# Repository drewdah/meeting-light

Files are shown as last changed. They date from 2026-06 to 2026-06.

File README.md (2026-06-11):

# Meeting Light
A professional office status display for a Waveshare ESP32-C6 1.8" Touch AMOLED, mounted in an office window. Shows your current status — Available, In a Meeting, Working From Home, Out of Office, or a custom message — to coworkers passing by.

<p align="center">
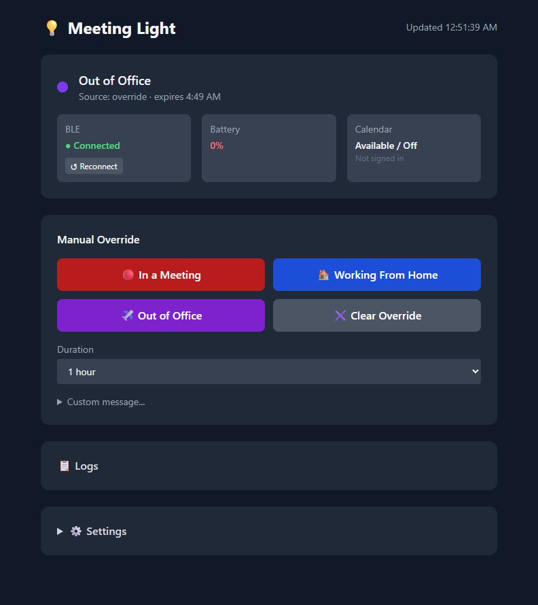
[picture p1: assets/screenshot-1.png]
Meeting Light web UI
  
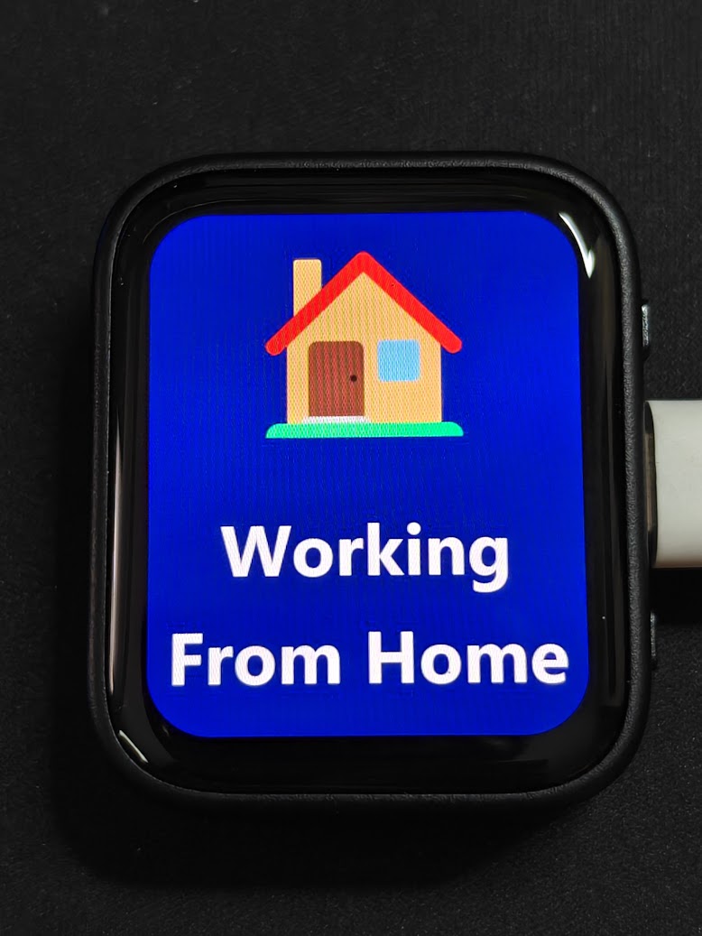
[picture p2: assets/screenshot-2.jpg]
Meeting Light on device
  
</p>

## How It Works

A mini PC at your desk polls your Outlook calendar via the Microsoft Graph API and pushes status updates to the ESP32 over BLE. A web UI (accessible remotely via Tailscale) lets you set manual overrides, compose custom messages with emoji, and preview what will appear on screen before sending.

```
ESP32-C6 AMOLED  <──BLE──>  Mini PC Service  <──Graph API──>  Microsoft 365
                                   │
                             Web UI :8080  <──Tailscale──  Remote access
```

## Features

- **Automatic detection** — polls Outlook or Google calendar for meetings, WFH location, and Out of Office status; shows **Available** when in the office with no active meeting
- **Emoji + text display** — full-resolution images rendered service-side with any emoji and custom text, transferred to the display over BLE
- **Full emoji picker** — pick any emoji from the web UI; no pre-compilation required
- **Preview before send** — see exactly what will appear on screen, with font size +/− controls
- **Calendar info card** — dashboard shows signed-in user, Teams presence, work location, and upcoming meetings at a glance
- **Manual overrides** — preset buttons (Available, In a Meeting, WFH, OOF) or custom message with background color and emoji
- **Override expiry** — set duration (30 min, 1 hr, end of day, etc.) before reverting to calendar state
- **Boot button controls** — tap to cycle through preset states; hold 3 seconds to reboot
- **Boot splash** — shows a 💡 Meeting Light logo on startup while connecting to the service
- **Waiting to Connect screen** — after the splash, shows a Bluetooth logo and the device's BLE MAC address so multiple units can be identified and configured
- **Per-device BLE name** — each device advertises as `MeetingLight-XXXX` (last 2 MAC bytes) for easy identification in BLE scanners and the service UI
- **Battery-safe deep sleep** — on battery power, sleeps and wakes every 2 minutes to advertise; never sleeps when USB is connected
- **Business hours scheduling** — device sleeps outside M–F 9–5; configurable in the web UI
- **Power monitoring** — live battery %, voltage, charging state, and USB power detection reported via BLE; dashboard shows USB Powered, Charging, or battery % as appropriate
- **Brightness control** — adjustable in Settings, applied immediately to the device
- **Real-time log panel** — connection and transfer logs visible in the web UI
- **Remote access** — web UI accessible via Tailscale from anywhere

## Display States

| State | Emoji | Background |
|---|---|---|
| Available | ☀️ | Green |
| In a Meeting | 🔴 | Red |
| Working From Home | 🏠 | Dark blue |
| Out of Office | ✈️ | Dark purple |
| Custom | Any emoji | Any color |
| Off | — | Screen off |

## Hardware

- [Waveshare ESP32-C6 Touch AMOLED 1.8"](https://www.waveshare.com/esp32-c6-touch-amoled-1.8.htm) — 368×448 AMOLED, BLE 5, two hardware buttons, LiPo connector
- Always-on mini PC at desk (Raspberry Pi, mini PC, etc.)
- 3000mAh LiPo battery, swappable; device deep-sleeps and wakes every 2 minutes to check for a connection

### Button Controls

The device has two buttons — **BOOT** (side) and **PWR** (side):

| Gesture | Action |
|---|---|
| Tap BOOT | Cycle through Off → In a Meeting → WFH → Out of Office → Available |
| Hold BOOT 3s | Reboot device |

## Enclosure

A two-piece 3D-printed case (designed in Fusion 360). Print files are in `enclosure/`:
`MeetingLight-Enclosure.3mf` (both parts, ready to import into Bambu Studio / PrusaSlicer) and individual STLs in `enclosure/stl/`.

- **Front Lid** — holds the screen and PIR sensor, and frames a paper name-plate insert. The display window is a **flush recess** so the raised cover glass sits level with the front face; a small countersunk aperture exposes the PIR's field of view without a large hole.
- **Back Tray** — holds the LiPo battery (retained by mid-edge ribs that keep the corners clear for the battery's JST wire) and mounts to a window with a command strip.
- **Joint** — the lid presses onto the tray with a self-aligning rabbet lip and snap-in detents (bumps on the lid that click into pockets in the tray walls). No screws; pops off by hand for battery swaps.
- **Overall size** — ~202 × 50 × 17 mm.

**Printing:** orient each part **standing on its end (long axis vertical)** to print without supports — the rabbet, pockets, and screen recess are all designed for that orientation. PLA/PETG, 0.2 mm layers. Detent strength is tunable: if the lid is too stiff or too loose, adjust the bump height slightly and re-export.

## Project Structure

```
firmware/       # ESP32-C6 firmware (PlatformIO + Arduino)
service/        # Mini PC service (Python + FastAPI + Docker)
enclosure/      # 3D-printed two-piece case (STL + 3MF, designed in Fusion 360)
docs/           # Architecture plan and documentation
```

## Getting Started

### Windows USB Driver Note

The ESP32-C6 uses a built-in USB-Serial/JTAG controller. On Windows, if the device doesn't appear as a COM port, install the [ESP32 board support package in Arduino IDE](https://docs.espressif.com/projects/arduino-esp32/en/latest/installing.html) which installs the correct Windows USB drivers. A reboot is required after installation.

### Firmware

Requires [PlatformIO](https://platformio.org/) with the [pioarduino](https://github.com/pioarduino/platform-espressif32) platform fork for ESP32-C6 Arduino support. The easiest approach is the PlatformIO VS Code extension.

```bash
cd firmware
pio run                          # build
pio run -t upload --upload-port COM9   # flash via USB-C (adjust port)
```

To regenerate the pre-compiled preset and boot splash images (run from repo root after changing the service rendering):
```bash
python3 firmware/tools/gen_preset_images.py   # Available, In a Meeting, WFH, OOF
python3 firmware/tools/gen_boot_splash.py     # Boot splash
```
Then reflash the firmware.

### Service

#### Prerequisites

- Python 3.11 or newer
- Bluetooth adapter (built-in or USB dongle)
- On Windows: no extra drivers needed; on Linux: `bluez` must be installed (`sudo apt install bluez`)

#### 1. Copy and edit `.env`

```bash
cd service
cp .env.example .env
```

Open `.env` and fill in your values — everything here is passed as environment variables to the container by `docker-compose`:

| Variable | Required | Description |
|---|---|---|
| `ESP32_MAC_ADDRESS` | Always | BLE MAC of your device (see *Finding Your ESP32 MAC Address* below) |
| `CALENDAR_PROVIDER` | Always | `microsoft` (default) or `google` |
| `MS_GRAPH_CLIENT_ID` | Microsoft | Azure public-client app ID — see *One-time provider setup* |
| `MS_GRAPH_TENANT_ID` | Microsoft | Your tenant GUID (Directory ID from Azure app registration Overview) |
| `GOOGLE_CLIENT_ID` | Google | OAuth client ID from Google Cloud — see *One-time provider setup* |
| `GOOGLE_CLIENT_SECRET` | Google | OAuth client secret (confidential — never commit) |
| `TIMEZONE` | Optional | IANA timezone, e.g. `America/New_York` |

#### 2. Create a virtual environment and install dependencies

```bash
# Windows
python -m venv .venv
.venv\Scripts\activate

# macOS / Linux
python3 -m venv .venv
source .venv/bin/activate
```

```bash
pip install -r requirements.txt
```

#### 3. Run the service

```bash
python -m uvicorn src.web.app:app --host 0.0.0.0 --port 8080
```

The web UI is available at `http://localhost:8080` (or `http://<your-pc>:8080` from another device on the same network / via Tailscale).

#### 4. Authenticate your calendar (first run)

1. Open the web UI and go to **⚙️ Settings → Calendar**.
2. Select your provider and click **Sign In**.
3. A device code will appear — visit the URL shown and enter the code in your browser.
4. Once authenticated the service starts polling your calendar automatically. Tokens are cached in `data/` and refreshed on subsequent runs.

#### Docker (production mini PC deployment)

```bash
docker compose up
```

The same `.env` file is used; Docker Compose passes it through automatically.

### Calendar Provider

Set `CALENDAR_PROVIDER=microsoft` (default) or `CALENDAR_PROVIDER=google` in `.env`.

The app is pre-registered for both providers — each deployer just picks a provider and
signs in; there's no cloud console work per deployment. Each person authenticates with
their own Microsoft/Google account via the sign-in flow in the web UI.

**What gets detected (priority order):**
- **Working From Home** — Teams/Outlook work location set to Home (Microsoft presence API), all-day WFH events, or [Working Location](https://support.google.com/calendar/answer/11896660) → Home Office (Google)
- **Out of Office** — OOF events or scheduled automatic replies (Microsoft); native Out of Office events (Google)
- **In a Meeting** — any busy/tentative calendar event happening right now
- **Available** — in the office with no active meeting (Microsoft only; Google defaults to Available)

#### Google Testing Mode limit

`calendar.readonly` is a Google "sensitive" scope. Until the app completes Google's
one-time verification, it runs in **Testing mode**, which means:
- Maximum **100 users** across all deployments (app-wide, not per host)
- Refresh tokens **expire every 7 days** — Gmail users must re-sign-in weekly

Each Gmail user must be added as a test user in [Google Cloud Console → OAuth consent screen](https://console.cloud.google.com/). Microsoft 365 / Outlook has no equivalent limit.

### One-time provider setup (maintainer only)

Register the app once; every deployment reuses the same credentials via `.env`. Each user
then signs in with their own account — no per-person cloud console work required.

**Microsoft** — [portal.azure.com](https://portal.azure.com) → **Microsoft Entra ID** → **App registrations** → **New registration**:

1. **Name**: anything (e.g. `Meeting Light`)
2. **Supported account types**: choose based on your account type:
   - Work/school (Microsoft 365): *Accounts in this organizational directory only*
   - Personal (Outlook.com/Hotmail) or mixed: *Accounts in any organizational directory … and personal Microsoft accounts*
3. **Redirect URI**: leave blank — click **Register**
4. Copy the **Application (client) ID** → `MS_GRAPH_CLIENT_ID` in `.env`
5. Go to **Authentication** (left sidebar):
   - Click **Add a platform** → **Mobile and desktop applications**
   - Check `https://login.microsoftonline.com/common/oauth2/nativeclient` → **Configure**
   - Scroll down to **Advanced settings** → set **Allow public client flows** to **Yes** → **Save**
6. Go to **API permissions** (left sidebar):
   - Click **Add a permission** → **Microsoft Graph** → **Delegated permissions**
   - Search and add: `Calendars.Read`, `Presence.Read`, `User.Read`, `MailboxSettings.Read`
   - Click **Grant admin consent** if the button appears (required for org accounts)

> **Tenant ID note**: set `MS_GRAPH_TENANT_ID` to your actual tenant GUID (visible on the app registration Overview page as *Directory (tenant) ID*). `organizations` does not work for single-tenant registrations. Use `common` only for multi-tenant apps that allow personal Microsoft accounts.

**Google** — [console.cloud.google.com](https://console.cloud.google.com) → new project:
- Enable the **Google Calendar API**
- Credentials → OAuth client ID → type: **TV and Limited Input devices**
- Copy the **Client ID** → `GOOGLE_CLIENT_ID` in `.env`
- Copy the **Client Secret** → `GOOGLE_CLIENT_SECRET` in `.env` (confidential — never commit)
- Add each Gmail user as a test user on the OAuth consent screen

### Finding Your ESP32 MAC Address

Power on the device — after the boot splash it shows a **"Waiting to Connect"** screen with the Bluetooth logo and the full MAC address (e.g. `FC:01:2C:FD:DD:E0`). Read it directly off the screen.

Alternatively, run the BLE scanner:
```bash
cd service
python scan.py
```
The device advertises as `MeetingLight-XXXX` (last 2 MAC bytes). Set `ESP32_MAC_ADDRESS` in `.env`, or enter it in the web UI under ⚙️ Settings and click **↺ Reconnect**. The service will also auto-discover any `MeetingLight-XXXX` device if no MAC is configured.

### Deploying on Proxmox (Docker in LXC)

This setup runs the service inside a Docker container inside a **privileged LXC container** on a Proxmox node. Bluetooth is provided by the Proxmox host's BlueZ via a shared D-Bus socket — the LXC container gets a working `/run/dbus` without running BlueZ itself.

#### Prerequisites on the Proxmox host

1. **Install BlueZ on the host** (not inside the LXC):
   ```bash
   apt install bluez
   systemctl enable --now bluetooth
   ```

2. **Bind the host D-Bus socket into the LXC** — edit `/etc/pve/lxc/<id>.conf`:
   ```
   lxc.cgroup2.devices.allow: a
   lxc.cap.drop:
   lxc.mount.entry: /dev/bus/usb dev/bus/usb none bind,optional,create=dir
   lxc.mount.entry: /dev/rfkill dev/rfkill none bind,optional,create=file
   lxc.mount.entry: /run/dbus mnt/host-dbus none bind,create=dir
   ```
   > The `/run/dbus` → `/mnt/host-dbus` indirection is required because `/run` inside the LXC is a tmpfs that gets mounted after LXC bind mounts are processed.

3. **Create a systemd mount unit inside the LXC** (`/etc/systemd/system/run-dbus.mount`) to relay the socket into `/run/dbus` at boot:
   ```ini
   [Unit]
   Description=Bind mount host BlueZ D-Bus socket
   DefaultDependencies=no
   After=tmp.mount

   [Mount]
   What=/mnt/host-dbus
   Where=/run/dbus
   Type=none
   Options=bind

   [Install]
   WantedBy=sysinit.target
   ```
   ```bash
   systemctl enable run-dbus.mount
   ```

#### Deploying the service inside the LXC

```bash
# Inside the LXC
apt install docker.io docker-compose-plugin git

# Fix Docker cgroup driver (required in LXC)
mkdir -p /etc/docker
echo '{"exec-opts": ["native.cgroupdriver=cgroupfs"]}' > /etc/docker/daemon.json
systemctl restart docker

# Clone and configure
git clone https://github.com/drewdah/meeting-light /opt/meeting-light
cp /opt/meeting-light/service/.env.example /opt/meeting-light/service/.env
# Edit .env with your MS_GRAPH_CLIENT_ID, MS_GRAPH_TENANT_ID, TIMEZONE, etc.

cd /opt/meeting-light/service
docker compose up -d
```

> **Note**: If you update `.env`, run `docker compose up -d --force-recreate` — `docker compose restart` does not reload environment files.

#### Docker Compose network mode

The service's `compose.yml` uses `network_mode: host` and `privileged: true` so the container has direct access to the LXC's D-Bus socket (`/run/dbus`) and the shared Bluetooth adapter.

## Configuration

All settings are configurable in the web UI under ⚙️ Settings:

| Setting | Default | Description |
|---|---|---|
| Business hours start | 9 | Hour (24h) to wake device |
| Business hours end | 17 | Hour (24h) to sleep device |
| Timezone | America/New_York | IANA timezone string |
| ESP32 MAC address | — | BLE MAC of the device |
| Poll interval | 60s | How often to check calendar |
| Brightness | 128 | Display brightness 0–255 |

## Architecture Notes

- **State priority**: Manual override > WFH (work location/all-day event) > OOF (auto-reply/event) > In a Meeting > Available > Schedule (sleep) > Off
- **Image transfer**: Service renders full 368×448 JPEG using Pillow (Segoe UI Emoji on Windows), transfers in ~490-byte acknowledged BLE chunks
- **Preset images**: Available, In a Meeting, WFH, OOF, and the boot splash are pre-compiled as JPEG byte arrays in firmware (`preset_images.h`, `boot_splash.h`). The boot button cycles through these instantly with no BLE transfer. Re-run the generator scripts and reflash to update them.
- **BLE**: NimBLE peripheral on ESP32, bleak central on mini PC. Custom GATT service with state command + device status characteristics
- **Power**: AXP2101 PMIC reports battery %, voltage, charging state, and USB/VBUS presence over BLE. AMOLED with mostly-dark backgrounds; device deep-sleeps and wakes every 2 minutes to advertise BLE. Deep sleep is skipped entirely when USB power is connected (VBUS detected). Hardware note: GPIO wakeup from deep sleep requires LP GPIOs (0–7) on ESP32-C6 — all are consumed by the display bus and I2C, so only RTC timer wakeup is available.

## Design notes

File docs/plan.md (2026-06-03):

# Meeting Light System - Implementation Plan

## Context

The user wants a professional-looking status display for their office window that shows coworkers (primarily CEO and HR) whether they're in a meeting, working from home, or out of office. The system uses a Waveshare ESP32-C6 1.8" Touch AMOLED (battery-powered, BLE only) controlled by a Linux mini PC at the desk that polls Outlook calendar via Microsoft Graph API. A web UI on the mini PC (accessible remotely via Tailscale) allows manual overrides and custom messages/images.

## Architecture

```
┌──────────────┐  BLE   ┌──────────────────┐  Graph API  ┌─────────────┐
│  ESP32-C6    │◄──────►│  Mini PC Service  │◄───────────►│  Microsoft  │
│  AMOLED      │        │  (Docker)         │             │  365        │
│  display     │        │                   │             └─────────────┘
└──────────────┘        │  Web UI :8080     │◄── Tailscale ── User (remote)
                        └──────────────────┘
```

**State priority**: Manual override (web UI/buttons) > Calendar-detected > Schedule-based (sleep outside hours) > Off

## Project Structure

```
meeting-light/
├── firmware/                    # ESP32-C6 (PlatformIO + ESP-IDF)
│   ├── platformio.ini
│   ├── src/
│   │   ├── main.cpp
│   │   ├── ble_service.h/.cpp   # NimBLE GATT server
│   │   ├── display.h/.cpp       # SH8601 AMOLED via esp_lcd
│   │   ├── power.h/.cpp         # AXP2101 PMIC, deep sleep
│   │   ├── state.h/.cpp         # Local state + NVS persistence
│   │   └── buttons.h/.cpp       # GPIO interrupt + debounce
│   └── include/
│       └── config.h             # Pin defs, BLE UUIDs, constants
├── service/                     # Mini PC (Python + FastAPI)
│   ├── Dockerfile
│   ├── docker-compose.yml
│   ├── requirements.txt
│   ├── src/
│   │   ├── main.py
│   │   ├── config.py
│   │   ├── graph_client.py      # MS Graph polling (MSAL + aiohttp)
│   │   ├── ble_client.py        # BLE central (bleak)
│   │   ├── state_machine.py     # State engine with priorities
│   │   ├── scheduler.py         # Business hours logic
│   │   ├── image_processor.py   # Resize/compress images for BLE
│   │   └── web/
│   │       ├── app.py           # FastAPI + routes
│   │       ├── static/
│   │       └── templates/       # Jinja2 + HTMX
│   └── tests/
└── docs/
```

## Technology Choices

| Component | Choice | Why |
|---|---|-----|
| ESP32 framework | ESP-IDF v5.3+ via PlatformIO | Full control over NimBLE power save, AXP2101 PMIC, deep sleep |
| ESP32 BLE stack | NimBLE | ~50KB less RAM than Bluedroid, built-in power save |
| Display driver | `esp_lcd` + `esp_lcd_sh8601` | Official Espressif QSPI component for SH8601 |
| Mini PC language | Python 3.12+ | Best MS Graph SDK (MSAL), excellent BLE lib (bleak), async-native |
| Web framework | FastAPI + Jinja2 + HTMX + Tailwind | Server-rendered, no JS build step, HTMX for dynamic updates |
| BLE library (PC) | bleak | Cross-platform async BLE, works in Docker with host BT passthrough |
| Graph auth | MSAL device code flow | Right pattern for headless service, auto token refresh |
| Container | Docker with `--net=host` + privileged | Required for BlueZ/BLE access |

## BLE Protocol

Custom GATT service with three characteristics:

**State Command (Write)** - opcodes:
- `0x01 SET_PRESET_STATE [state_id]` — 0=Off, 1=In Meeting, 2=WFH, 3=OOF
- `0x02 SET_CUSTOM_TEXT [r][g][b][utf8 text]` — colored background + text
- `0x03 SLEEP` — enter deep sleep
- `0x05 IMAGE_START [size][w][h][format]` — begin image transfer
- `0x06 IMAGE_CHUNK [index][payload]` — chunked data (write-without-response for speed)
- `0x07 IMAGE_END [crc32]` — finalize + verify
- `0x08 SET_BRIGHTNESS [0-255]`

**Device Status (Read + Notify)** — current state, battery %, charging flag, voltage. ESP32 notifies on every state change (serves as ACK) and periodically while awake.

**Image transfer**: Service compresses to JPEG (~30KB for 368x448), sends in ~507-byte chunks at ~50-100 KB/s. Transfer completes in under 1 second.

## Web UI

**Dashboard**: Current state, battery level, BLE connection status, Graph API status, active override countdown.

**Override panel**: Preset buttons, custom text input + color picker, image upload with preview/crop, duration selector (30m / 1h / 2h / end of day / until next calendar change / indefinite).

**Settings**: Business hours, timezone, Graph re-auth, ESP32 MAC, brightness slider, transition log.

**API endpoints** (for automation): `GET /api/status`, `POST /api/override`, `DELETE /api/override`, `GET /api/history`.

## Power Management

- **Business hours only (M-F 9-5)**: ESP32 deep sleeps nights and weekends
- **AMOLED efficiency**: All-day statuses (WFH/OOF) use mostly-black backgrounds to save power. Short-lived statuses (In Meeting) use bold colors to catch the eye of passersby. 30-50% brightness.
- **Duty cycling for all-day statuses (WFH/OOF)**: Screen on for 30s, off/dim for 90-120s, repeat. Meetings skip duty cycling (screen stays on for full duration since they're short-lived).
- **BLE tuning**: 1s connection interval idle, 100ms during image transfer, slave latency 4
- **Disable unused peripherals**: Touch controller (screen faces window), IMU (unless used for subtle burn-in prevention)
- **Target**: 1000mAh+ LiPo, battery-only operation, 1+ week battery life with duty cycling
- **Burn-in prevention**: Subtle 1-2px random shift every few minutes

## Microsoft Graph Integration

**Azure AD app registration** with delegated permissions: `Calendars.Read`, `Presence.Read`, `User.Read`, `MailboxSettings.Read`.

**Detection logic** (polled every 60s):
1. `calendarView` for current time window — busy/tentative non-all-day events = In Meeting
2. `showAs == "oof"` = Out of Office
3. Work location / all-day event location containing "home"/"remote" = WFH
4. Default = Off

**First-time auth**: Service shows device code on web UI and logs, user completes in browser, tokens cached and auto-refreshed.

## Implementation Phases

### Phase 1: ESP32 display proof-of-concept
- PlatformIO project, SH8601 init, display a static test image
- AXP2101 battery reading, deep sleep + button wake

### Phase 2: ESP32 BLE peripheral
- NimBLE GATT server, handle SET_PRESET_STATE
- ACK with battery level, test with nRF Connect app

### Phase 3: Mini PC BLE client
- Python + bleak, scan/connect/send commands
- Docker container with Bluetooth passthrough
- Verify round-trip command + ACK

### Phase 4: Web UI basics
- FastAPI + HTMX dashboard
- Connection/battery status display
- Preset override buttons with expiry timer

### Phase 5: Microsoft Graph integration
- MSAL device code auth flow
- Calendar polling + state machine
- Business hours scheduling

### Phase 6: Custom text and image support
- ESP32: text rendering with embedded font, JPEG decode (TJpgDec)
- Service: image upload/resize/compress, chunked BLE transfer
- Web UI: image upload, text input + color picker

### Phase 7: Polish and hardening
- Power optimization tuning
- Auto-reconnect on BLE disconnect
- Error handling, logging, settings page
- State transition history

### Phase 8: Production readiness
- Preset image design (professional graphics)
- Setup documentation
- Real Outlook calendar testing

## Key Risks

1. **BLE from Docker** — BlueZ in containers is finicky. Test in Phase 3 early. Fallback: run service on host with systemd.
2. **Deep sleep current** — Real-world with AXP2101 may be ~300uA vs 7uA spec. No power outlet near the window, so battery is the only option. Mitigate by disabling all unused peripherals and using 1000mAh+ LiPo. Accept weekly battery swaps.
3. **SH8601 driver** — Espressif component is v0.0.1. Fallback: port Waveshare's Arduino demo init sequence to ESP-IDF.
4. **Enterprise Graph API** — Some orgs restrict app registrations. Document exact permissions needed.
5. **AMOLED burn-in** — Mitigated by pixel shifting, dark backgrounds, and screen-off during idle.

## Verification

- **ESP32**: Flash firmware, verify display shows preset images, BLE connects from nRF Connect, battery reading is sane, deep sleep current measured with multimeter
- **Service**: `docker compose up`, authenticate via device code, verify calendar events are detected, state transitions appear in web UI, BLE commands reach ESP32
- **End-to-end**: Create a test meeting in Outlook, verify ESP32 shows "In Meeting" within 60s, verify it clears when meeting ends. Set WFH in calendar, verify display updates. Test manual override from web UI and verify it takes priority. Test override expiry reverts to calendar state.

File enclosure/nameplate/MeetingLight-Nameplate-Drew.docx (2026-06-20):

Meeting Light — Nameplate Insert

Final cut size: 194 × 46 mm (≈ 7‑ 5/8″ × 1‑ 13/16″). Slides into the right-hand channel of the front lid.

▼ Edit the text, then cut along the solid line ▼

Drew Lawton

Director of Data & Tech Operations

Solid line = cut here (194 × 46 mm). The top & bottom ~1.7 mm tucks under the retaining lips, so keep important text vertically centered (it already is).

How to use

1. Click inside the box and replace the placeholder with your name / status. Keep it vertically centered so nothing important hides under the lips.
2. Print at 100% / “Actual size.” Turn OFF “Fit to page” / “Shrink oversized pages.”
3. Check scale: the bar below should measure exactly 50 mm. If not, fix the print-scaling setting and reprint.
4. Cut along the solid outer rectangle — final piece is 194 × 46 mm.
5. Slide it into the right-hand channel of the front lid, entering from the screen end, until it stops at the far wall.

Print-scale check bar:

50 mm

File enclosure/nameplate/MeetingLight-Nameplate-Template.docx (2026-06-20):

Meeting Light — Nameplate Insert

Final cut size: 193 × 46 mm (≈ 7‑ 5/8″ × 1‑ 13/16″). Slides into the right-hand channel of the front lid.

▼ Edit the text, then cut along the solid line ▼

Drew Lawton

Director of Data & Tech Operations

Solid line = cut here (193 × 46 mm). Dashed line = visible window (~194 × 42.6 mm) — keep important text inside it; the ~1.7 mm above & below tucks under the retaining lips.

How to use

1. Click inside the box and replace the placeholder with your name / status. Font auto-centers; size it to fit inside the dashed window.
2. Print at 100% / “Actual size.” Turn OFF “Fit to page” / “Shrink oversized pages.”
3. Check scale: the bar below should measure exactly 50 mm. If not, fix the print-scaling setting and reprint.
4. Cut along the solid outer rectangle — final piece is 193 × 46 mm.
5. Slide it into the right-hand channel of the front lid, entering from the screen end, until it stops at the far wall.

Print-scale check bar:

50 mm

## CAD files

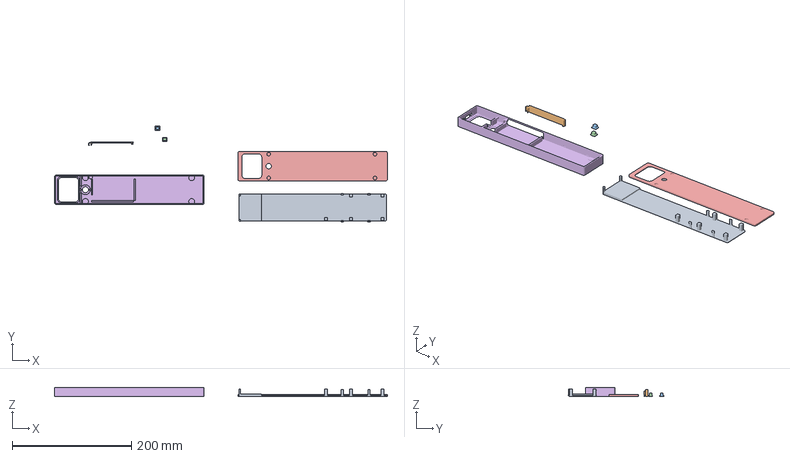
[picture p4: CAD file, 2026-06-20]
enclosure/MeetingLight-Enclosure.3mf
558.2 x 160.5 x 14.8 mm
Back Retainer
Battery Door
ButtonCap_1
ButtonCap_2
Front Cover
Front Lid

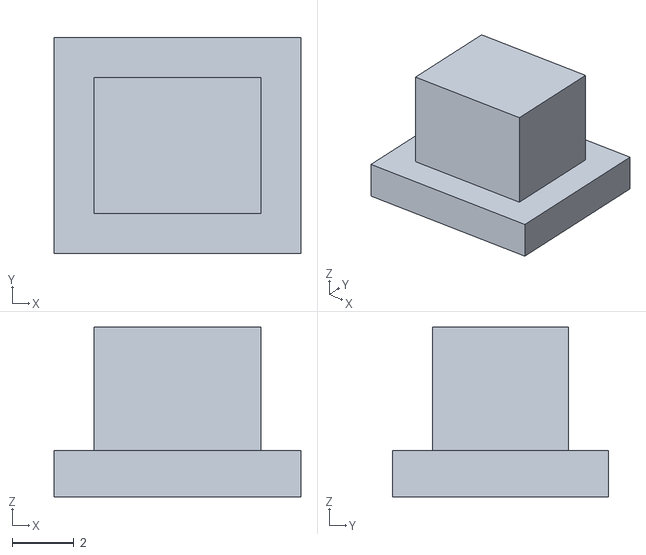
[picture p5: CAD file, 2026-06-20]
enclosure/stl/ButtonCap_1.stl
8.00 x 7.00 x 5.50

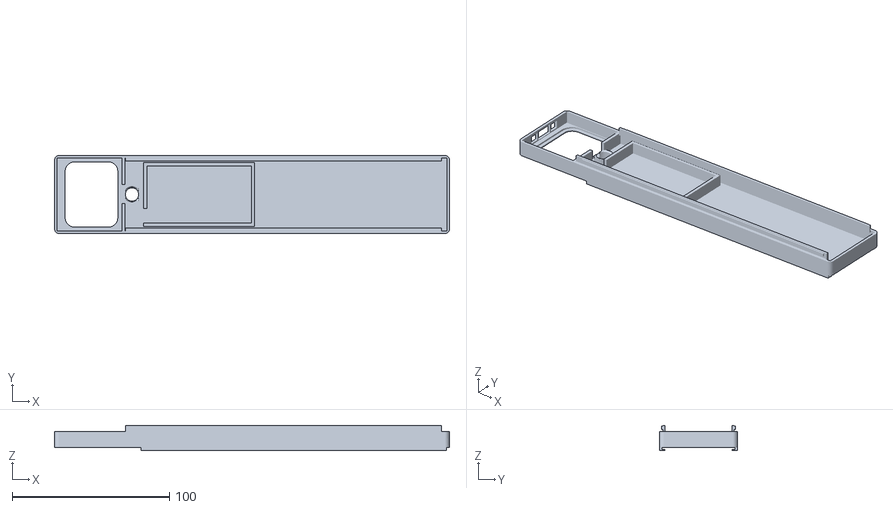
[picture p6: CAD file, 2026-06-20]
enclosure/stl/FrontLid.stl
251.0 x 49.6 x 16.0

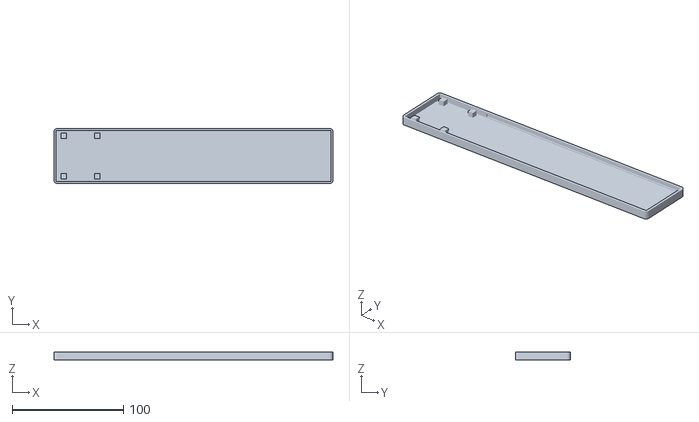
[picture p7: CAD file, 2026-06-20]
enclosure/stl/Back Tray.stl
251.0 x 49.6 x 7.00

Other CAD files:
enclosure/MeetingLight-Enclosure-v11.f3d

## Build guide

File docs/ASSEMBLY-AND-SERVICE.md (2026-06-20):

# Meeting Light — Assembly & Service Cheat Sheet

Quick reference for building, wiring, and servicing the Meeting Light enclosure.
Dimensions are measured from the current `enclosure/stl/FrontLid.stl` (v11). Last updated 2026-06-11.

---

## 1. Nameplate paper insert

| Spec | Value |
|---|---|
| **Cut size** | **194 × 46 mm** (≈ 7‑5/8″ × 1‑13/16″) |
| Visible window | ~194 × 42.6 mm (the top & bottom ~1.7 mm tuck under the retaining lips) |
| Channel location | Right-hand zone of the front lid, **X55 → X249** |
| Insertion | Slides in from the **screen end**, stops at the far wall |
| Template | [`enclosure/nameplate/MeetingLight-Nameplate-Drew.docx`](../enclosure/nameplate/MeetingLight-Nameplate-Drew.docx) |

**Printing:** Print at **100% / "Actual Size"** — turn OFF "Fit to page" / "Shrink oversized pages."
Verify with the **50 mm check bar** on the template: if it doesn't measure exactly 50 mm with a ruler, your printer is scaling and the insert will come out short. Fix the scale setting and reprint.

---

## 2. PIR sensor (AM312) — wiring & connector

### Wiring
| PIR pin | Connects to | Notes |
|---|---|---|
| **VIN** | **3V3** | Power at 3.3 V, **not 5 V** (keeps OUT at a safe 3.3 V logic level) |
| **OUT** | **GPIO17** | `PIR_PIN 17` in [`firmware/include/config.h`](../firmware/include/config.h) |
| **GND** | **GND** | |

- ⚠️ **AM312 pin order varies by board** (`GND-OUT-VCC` vs `VCC-OUT-GND`). Match **your** board's silkscreen — do not trust an online photo or a connector's "pin 1."
- The PIR is **not a wake source** — it's read while the screen is already awake to drive the sleep timeout (`PIR_TIMEOUT_MS = 60000`, 1 min no-motion → display off). A cold/iffy joint just shows up as "no motion" in the logs; low-consequence to get wrong on the first try and reflow.

### Make it swappable (one connector, at the PIR)
You only need ONE connector. Solder the pigtail to the board **once**; the connector at the PIR end is what makes the sensor swappable.

```
ESP32 board ──solder once──┐                       ┌── PIR sensor
 GPIO17 ──────────────────[ wires ]──[ connector ]── 3-pin header
 3V3   ──────────────────[ wires ]──[  (keyed)  ]──
 GND   ──────────────────[ wires ]──┘                       └──
        (do this once)                unplug here to swap the PIR
```

**Path 1 — fastest, no crimp tool, no soldering the PIR:** a 3‑pin **servo extension lead**. Female end plugs onto the PIR's existing 0.1″ pins (semi-keyed); cut the male end off and solder those 3 wires to the board.

**Path 2 — keyed JST‑XH, the "do it once properly" version:** solder a 3‑pin **XH PCB header** onto the PIR, crimp an XH pigtail (keyed + latched, can't reverse-power), plug together, solder the pigtail's other end to the board. Needs a crimp tool (reusable).

> ⚠️ **Connector clearance:** the PIR sits in the slotted collar with pins clipped short. A bulky connector body may not fit right behind the PCB. The servo housing is chunkiest; JST‑XH is more compact; a **right-angle XH header** is best. If tight, put the connector a few cm away on short flying leads, out in the open lid cavity over the nameplate.

### Soldering checklist (the screen is NOT electrically at risk — these 3 nets don't touch the AMOLED)
1. **Power off, unplug USB, disconnect the battery** first.
2. **Pre-tin** the pad AND the wire separately, then join in ~1 s. (This is the anxiety-killer — no juggling.)
3. **Hot & fast:** ~350–370 °C, in and out under 2 s per joint. A *cool* iron held for 8 s does far more damage than a hot one for 2.
4. Use **thin 30 AWG silicone wire** — it won't lever the pad up like stiff wire.
5. **Protect the glass:** board face-down on a microfiber cloth, no hard point pressing under the AMOLED.
6. **Strain relief:** dab of hot glue / strip of Kapton over the wires.
7. **Verify before power:** loupe for solder bridges; multimeter continuity check that 3V3 / GND / GPIO17 aren't shorted to each other.

---

## 3. Battery — service extension cable

The board's battery port is an **MX1.25 2-pin** connector (1.25 mm pitch — confirmed on the
[Waveshare ESP32‑C6‑Touch‑AMOLED‑1.8 wiki](https://docs.waveshare.com/ESP32-C6-Touch-AMOLED-1.8)).
The on-board JST is tiny and awkward to cycle. Fix: plug a **male-to-female extension** into the board **once**, leave it, and do all battery swaps at the accessible extension end.

### ⚠️ Polarity — the one connector where a mistake can damage hardware
The extension only needs to be **straight-through (red → red, black → black)**. If it is, it's electrically invisible — whatever orientation your battery plugs in directly today works identically through it.

Before the **first** battery connection through the extension:
1. **Trace the wire colors** at both housings — red must land on the same pin at each end.
2. Better, **meter it:** continuity from one end's red pin to the other end's red pin; confirm red is NOT tied to black.
3. **Dry-fit unpowered:** one end must plug into the board where the battery was; the other end must accept the battery's plug.

### Practical notes
- **Strain-relieve the board end** (hot glue / Kapton) — that tiny MX1.25 is fragile and you'll never unplug it again, so don't let months of tugging stress its solder pads.
- **Never short the loose leads.** Treat the bare cell with respect; never bridge the two contacts with a tool.
- 20 cm is generous — coil the slack behind the nameplate area (it's empty) or trim-to-length later (after confirming fit + function).

---

## 4. Parts list (Amazon)

> Links were live as of 2026-06-11; verify contents/photos before buying — "male/female" naming on these is inconsistent. The links are listings, not endorsements.

### PIR connector
| Path | Part | Link |
|---|---|---|
| 1 (simplest) | 3‑pin servo male-to-female leads, 150 mm (10‑pk) | [B08RDNF5ZK](https://www.amazon.com/10pcs-Servo-Extension-Female-Futaba/dp/B08RDNF5ZK) |
| 2 (keyed JST‑XH) | WayinTop SN‑28B crimp kit + JST‑XH + DuPont | [B07VND42CF](https://www.amazon.com/WayinTop-Crimping-Connector-Connectors-28-18AWG/dp/B07VND42CF) |
| 2 (alt) | SN‑28B tool + JST‑XH terminal kit (2010 pc) | [B0FM3NYHBH](https://www.amazon.com/Sn-28b-Crimping-Pliers-Set-1550pcs-Connector/dp/B0FM3NYHBH) |
| 2 (no tool) | daier JST‑XH 3‑pin set w/ wire — *confirm it includes a PCB header* | [B01DUC1PGC](https://www.amazon.com/Sets-2-5-3-Connector-200mm-Female/dp/B01DUC1PGC) |

### Battery extension
| Part | Link |
|---|---|
| **BHUPWZE MX1.25 2‑pin male-to-female extension, 20 cm (10‑pk)** — the one | [B0FZNRT2JT](https://www.amazon.com/BHUPWZE-MX1-25-Extension-1-25mm-Connector/dp/B0FZNRT2JT) |
| XUGERIP MX 1.25 2‑pin, pre-crimped 100 mm leads (backup) | [B0DMSYJZ4T](https://us.amazon.com/XUGERIP-1-25mm-Connector-Connectors-Extension/dp/B0DMSYJZ4T) |
| Cermant MX1.25 connector + pre-crimped cable kit (assortment) | [B0DSFNXRQ5](https://www.amazon.com/Cermant-MX1-25mm-Connectors-Pre-Crimped-Premium/dp/B0DSFNXRQ5) |

### Wire
| Part | Link |
|---|---|
| Striveday 30 AWG silicone hook-up wire | [B01KQ2JPY8](https://www.amazon.com/StrivedayTM-Flexible-Silicone-electronic-electrics/dp/B01KQ2JPY8) |
| TUOFENG 30 AWG silicone wire, 6 colors | [B07G2SWB19](https://www.amazon.com/TUOFENG-30awg-Stranded-Wire-Kit/dp/B07G2SWB19) |

---

## 5. Pin quick reference

| Signal | Pin | Source |
|---|---|---|
| PIR OUT | GPIO17 | `config.h` → `PIR_PIN` |
| BOOT button | GPIO9 (active LOW) | board |
| Touch INT | GPIO15 | board |
| I2C | SCL=7, SDA=8 | board |
| Battery | MX1.25 2‑pin, AXP2101 PMIC | board |

*Full hardware/firmware details live in the project memory overview and the repo `README`.*

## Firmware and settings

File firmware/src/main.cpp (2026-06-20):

#include <Arduino.h>
#include <Wire.h>
#include <esp_system.h>
#include "config.h"
#include "display.h"
#include "power.h"
#include "ble_service.h"
#include "state.h"
#include "buttons.h"
#include "audio.h"
#include "pir.h"

// Crash loop detection: RTC_NOINIT_ATTR survives software resets but is cleared on power-on.
// After 3 consecutive crash resets we enter safe mode (stable screen, no retry) to prevent
// USB re-enumeration thrashing that corrupts the Windows driver state.
#define CRASH_MAGIC    0xDEADC0DE
#define CRASH_LIMIT    3
#define SAFE_MODE_MS   30000  // reset counter after this many ms of clean uptime

RTC_NOINIT_ATTR static uint32_t crash_magic;
RTC_NOINIT_ATTR static uint32_t crash_count;

static bool safe_mode = false;
static unsigned long boot_ok_start = 0;
static bool audio_status_logged = false;

// Boot phase: track splash → waiting → done transition
enum BootPhase { BOOT_SPLASH, BOOT_WAITING, BOOT_DONE };
static BootPhase boot_phase = BOOT_DONE;
static unsigned long splash_start = 0;
static bool pir_display_blanked = false;

// Apply the saved NVS state to the display (used when exiting boot phases)
static void show_saved_state() {
    DisplayState saved = state_get_current();
    if (saved == STATE_OFF) {
        display_off();
    } else if (saved == STATE_IN_MEETING || saved == STATE_WFH ||
               saved == STATE_OOF       || saved == STATE_AVAILABLE) {
        display_on();
        display_show_preset(saved);
    } else {
        // CUSTOM_TEXT / CUSTOM_IMAGE: payload isn't persisted locally —
        // just turn the display on and wait for the app to push the content.
        display_on();
    }
}

static unsigned long last_battery_report = 0;
static const DisplayState PRESET_CYCLE[] = {
    STATE_OFF, STATE_IN_MEETING, STATE_WFH, STATE_OOF, STATE_AVAILABLE
};
static const uint8_t PRESET_COUNT = sizeof(PRESET_CYCLE) / sizeof(PRESET_CYCLE[0]);
static uint8_t cycle_index = 0;

static void on_boot_button() {
    pir_reset_timer();
    pir_display_blanked = false;

    cycle_index = (cycle_index + 1) % PRESET_COUNT;
    DisplayState new_state = PRESET_CYCLE[cycle_index];
    state_set(new_state);

    if (new_state == STATE_OFF) {
        display_off();
    } else {
        display_on();
        display_show_preset(new_state);
    }

    audio_play_state_chime();
    state_save_to_nvs();

    ble_notify_status(new_state,
                      power_get_battery_percent(),
                      power_is_charging(),
                      power_get_battery_mv(),
                      power_is_vbus_in(),
                      pir_motion_detected());

    Serial.printf("Button: state -> %d\n", new_state);
}

void setup() {
    Serial.begin(115200);
    // Wait up to 2s for CDC terminal so startup logs aren't silently dropped
    { uint32_t t = millis(); while (!Serial && (millis() - t) < 2000) delay(10); }
    delay(200);
    Serial.println("\n=== Meeting Light v0.1.0 ===");

    // Crash loop detection
    esp_reset_reason_t reset_reason = esp_reset_reason();
    bool is_crash_reset = (reset_reason == ESP_RST_PANIC ||
                           reset_reason == ESP_RST_WDT   ||
                           reset_reason == ESP_RST_TASK_WDT ||
                           reset_reason == ESP_RST_INT_WDT);

    if (reset_reason == ESP_RST_POWERON || crash_magic != CRASH_MAGIC) {
        crash_count = 0;
        crash_magic = CRASH_MAGIC;
    } else if (is_crash_reset) {
        crash_count++;
    }

    Serial.printf("Reset reason: %d, crash_count: %lu\n", reset_reason, crash_count);

    if (crash_count >= CRASH_LIMIT) {
        // Safe mode: minimal init only — stops USB thrashing
        Serial.printf("SAFE MODE: %lu consecutive crashes, halting\n", crash_count);
        Wire.begin(I2C_SDA, I2C_SCL, I2C_FREQ);
        power_init();
        display_init();
        display_show_custom_text("SAFE MODE\nHold BOOT 3s\nto restart", 255, 80, 0, 255, 255, 255);
        safe_mode = true;
        return;
    }

    // Check wake reason — timer wakes skip the splash/chime and go straight to connect screen
    esp_sleep_wakeup_cause_t wakeup = esp_sleep_get_wakeup_cause();
    bool from_timer_wake = (wakeup == ESP_SLEEP_WAKEUP_TIMER);
    if (from_timer_wake) {
        Serial.println("Woke from periodic deep sleep timer");
    } else if (wakeup != ESP_SLEEP_WAKEUP_UNDEFINED) {
        Serial.printf("Woke from deep sleep, cause: %d\n", wakeup);
    }

    Wire.begin(I2C_SDA, I2C_SCL, I2C_FREQ);

    power_init();
    state_init();
    display_init();
    buttons_init();
    pir_init();
    ble_init();
    audio_init();

    buttons_on_boot_press(on_boot_button);

    // Restore cycle_index so button cycling and BLE stay in sync.
    DisplayState saved = state_get_current();
    for (uint8_t i = 0; i < PRESET_COUNT; i++) {
        if (PRESET_CYCLE[i] == saved) {
            cycle_index = i;
            break;
        }
    }

    if (from_timer_wake) {
        // Periodic timer wake: skip splash and chime, go straight to connect screen.
        // This avoids playing audio every N minutes and makes the wake faster.
        String mac = ble_get_mac_address();
        display_show_waiting(mac.c_str());
        boot_phase = BOOT_WAITING;
    } else {
        // Fresh boot or hardware reset: full splash + chime sequence.
        display_show_boot_splash();
        audio_play_boot_chime();
        boot_phase = BOOT_SPLASH;
    }
    splash_start = millis();

    Serial.printf("Ready. State: %d, Battery: %d%% (%dmV)\n",
                  saved, power_get_battery_percent(), power_get_battery_mv());

    boot_ok_start = millis();
}

void loop() {
    if (safe_mode) {
        // Hold BOOT 3s still works via hardware reset; just idle here
        delay(100);
        return;
    }

    // Boot-phase sequencing: splash (5s) → waiting-to-connect → done
    if (boot_phase != BOOT_DONE) {
        bool connected_now = ble_is_connected();

        if (boot_phase == BOOT_SPLASH) {
            if (connected_now) {
                // Connected during splash — skip waiting screen, show saved state
                show_saved_state();
                boot_phase = BOOT_DONE;
            } else if (millis() - splash_start >= 5000) {
                // 5s elapsed, not yet connected — show waiting screen
                String mac = ble_get_mac_address();
                display_show_waiting(mac.c_str());
                boot_phase = BOOT_WAITING;
            }
        } else if (boot_phase == BOOT_WAITING) {
            if (connected_now) {
                // BLE connected while waiting — show saved state
                show_saved_state();
                boot_phase = BOOT_DONE;
            } else if (millis() - splash_start >= 30UL * 1000UL) {
                if (power_is_vbus_in()) {
                    // USB plugged in — stay awake indefinitely, keep the connect screen visible
                    splash_start = millis();
                } else {
                    // Battery only — sleep and retry on next timer wake (every 2 min)
                    Serial.println("No BLE connection — sleeping, will retry on timer wake");
                    state_set(STATE_OFF);
                    display_off();
                    power_enter_deep_sleep();
                    return;
                }
            }
        }
    }

    // Clear crash counter once we've been running cleanly long enough
    if (crash_count > 0 && boot_ok_start > 0 &&
        (millis() - boot_ok_start) > SAFE_MODE_MS) {
        crash_count = 0;
        boot_ok_start = 0;
    }

    // Log audio status once after BLE connects (startup logs missed during power cycle)
    if (!audio_status_logged && ble_is_connected()) {
        Serial.printf("Audio init: %s\n", audio_is_ok() ? "OK" : "FAILED");
        audio_status_logged = true;
    }

    buttons_check();

    pir_set_enabled(boot_phase == BOOT_DONE && !power_is_vbus_in());
    pir_update();

    // Execute any pending BLE command (deferred from BLE callback to avoid stack overflow)
    PendingCommand cmd;
    if (pending_get(cmd)) {
        if (cmd.sleep) {
            state_set(STATE_OFF);
            display_off();
            state_save_to_nvs();
            power_enter_deep_sleep();
            return;
        }
        if (cmd.brightness > 0) {
            display_set_brightness(cmd.brightness);
        }
        if (cmd.set_state) {
            pir_reset_timer();
            pir_display_blanked = false;

            state_set(cmd.state);
            audio_play_state_chime();
            if (cmd.state == STATE_OFF) {
                display_off();
            } else if (cmd.state == STATE_CUSTOM_TEXT) {
                display_on();
                display_show_custom_text(cmd.text, cmd.r, cmd.g, cmd.b,
                                         cmd.fg_r, cmd.fg_g, cmd.fg_b);
            } else if (cmd.state == STATE_CUSTOM_IMAGE) {
                display_on();
                display_show_image(ble_get_image_data(), ble_get_image_len());
                ble_free_image();
            } else {
                display_on();
                display_show_preset(cmd.state);
            }
        
            state_save_to_nvs();
            ble_notify_status(cmd.state,
                              power_get_battery_percent(),
                              power_is_charging(),
                              power_get_battery_mv(),
                              power_is_vbus_in(),
                              pir_motion_detected());
        }
    }

    // PIR display blanking (battery only, after boot)
    if (pir_is_enabled() && boot_phase == BOOT_DONE) {
        if (pir_display_blanked && pir_motion_detected()) {
            display_on();
            pir_display_blanked = false;
            pir_reset_timer();
            Serial.println("PIR: motion -> display on");
        } else if (!pir_display_blanked && display_is_on() && pir_has_timed_out()) {
            display_off();
            pir_display_blanked = true;
            Serial.println("PIR: timeout -> display off");
        }
    } else if (pir_display_blanked) {
        display_on();
        pir_display_blanked = false;
        Serial.println("PIR: disabled while blanked -> display on");
    }

    // Periodic battery status report
    unsigned long now = millis();
    if (now - last_battery_report > BATTERY_READ_INTERVAL_MS) {
        last_battery_report = now;
        if (ble_is_connected()) {
            ble_notify_status(state_get_current(),
                              power_get_battery_percent(),
                              power_is_charging(),
                              power_get_battery_mv(),
                              power_is_vbus_in(),
                              pir_motion_detected());
        }
    }

    delay(10);
}

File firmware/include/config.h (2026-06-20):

#pragma once

// --- QSPI Display (SH8601) ---
#define LCD_SCLK   0
#define LCD_SDIO0  1
#define LCD_SDIO1  2
#define LCD_SDIO2  3
#define LCD_SDIO3  4
#define LCD_CS     5

#define LCD_WIDTH  368
#define LCD_HEIGHT 448

// --- I2C Bus (shared by 6 devices) ---
#define I2C_SCL    7
#define I2C_SDA    8
#define I2C_FREQ   200000

// --- I2C Addresses ---
#define ADDR_TCA9554   0x20
#define ADDR_AXP2101   0x34
#define ADDR_FT3168    0x38
#define ADDR_PCF85063  0x51
#define ADDR_QMI8658   0x6B
#define ADDR_ES8311    0x18

// --- TCA9554 IO Expander ---
// P4 and P5 control display/touch power
#define TCA_DISP_TOUCH_P4  4
#define TCA_DISP_TOUCH_P5  5

// --- I2S / ES8311 Audio ---
// Verified against Waveshare ESP32-C6-Touch-AMOLED-1.8 official pin_config.h
#define I2S_MCLK   19
#define I2S_BCLK   20
#define I2S_WS     22
#define I2S_DOUT   23   // Data out ESP32→codec (speaker)
#define I2S_DIN    21   // Data in codec→ESP32 (mic, unused)
// PA amp enable is TCA9554 IO expander pin P7, not a direct GPIO
#define TCA_PA_CTRL  7
// ADDR_ES8311 (0x18) already defined above

// --- Buttons ---
#define BTN_BOOT   9   // Active LOW, strapping pin

// --- Touch ---
#define TOUCH_INT  15  // Active LOW, strapping pin

// --- BLE ---
#define BLE_DEVICE_NAME "MeetingLight"

#define BLE_SERVICE_UUID        "00001000-4d45-4554-4c49-544500000001"
#define BLE_CHAR_STATE_CMD_UUID "00001001-4d45-4554-4c49-544500000001"
#define BLE_CHAR_DEV_STATUS_UUID "00001002-4d45-4554-4c49-544500000001"
#define BLE_CHAR_DEV_INFO_UUID  "00001003-4d45-4554-4c49-544500000001"

// --- BLE Protocol Opcodes ---
#define OP_SET_PRESET      0x01
#define OP_SET_CUSTOM_TEXT 0x02
#define OP_SLEEP           0x03
#define OP_WAKE            0x04
#define OP_IMAGE_START     0x05
#define OP_IMAGE_CHUNK     0x06
#define OP_IMAGE_END       0x07
#define OP_SET_BRIGHTNESS  0x08
#define OP_PING            0x09
#define OP_SET_ICON_TEXT   0x0A  // [icon_id][r][g][b][text...]
#define OP_SET_MUTE        0x0B  // [0=unmute, 1=mute]

// --- Display States ---
// Values must match service/src/state_machine.py DisplayState enum
enum DisplayState : uint8_t {
    STATE_OFF = 0,
    STATE_IN_MEETING = 1,
    STATE_WFH = 2,
    STATE_OOF = 3,
    STATE_CUSTOM_TEXT = 4,
    STATE_CUSTOM_IMAGE = 5,
    // 6 = SLEEPING (service-side only, sent as OP_SLEEP not OP_SET_PRESET)
    STATE_AVAILABLE = 7,
};

// --- PIR Sensor (AM312) ---
#define PIR_PIN         17
#define PIR_TIMEOUT_MS  60000  // 1 min no-motion -> display off

// --- Power ---
#define BATTERY_READ_INTERVAL_MS  300000  // 5 minutes
#define DUTY_CYCLE_ON_MS          30000   // 30 seconds on
#define DUTY_CYCLE_OFF_MS         90000   // 90 seconds off

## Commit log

2026-06-04 Get display working on hardware: fix SH8601 init and use Adafruit_XCA9554
    - Fix Arduino_SH8601 constructor (remove spurious IPS argument that set width=0)
    - Replace raw I2C TCA9554 with Adafruit_XCA9554 library (matches official example)
    - Add Adafruit_BusIO as local lib dependency
    - Switch to pioarduino platform fork (55.03.38-1) for ESP32-C6 Arduino support
    - Add ARDUINO_USB_MODE=1 build flag for serial over USB-Serial/JTAG
    - Fix XPowersPMU -> XPowersAXP2101, ESP_EXT1_WAKEUP_ALL_LOW -> ANY_LOW
    - Enable BLDO1 at 3.3V in power_init for display power rail
    - Verified on hardware: display, button cycling, BLE advertising all working
    [ble_service.cpp, display.cpp, power.cpp]
2026-06-04 Add mini PC service: FastAPI + BLE client + Graph API + web dashboard
    - State machine with priority: override > calendar > schedule > default
    - BLE central client (bleak) with auto-reconnect and status notifications
    - Microsoft Graph API client with MSAL device code auth flow
    - Background scheduler: polls calendar every 60s, ticks every 30s
    - FastAPI web app with HTMX dashboard (auto-refreshes every 5s)
    - Preset override buttons, custom text with color picker
    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
2026-06-04 Add emoji icons, fix text centering, fix battery display
    Firmware:
    - Fix draw_centered_text: each line now individually centered (no more left-aligned text block)
    - Add display_show_icon_text: 120x120 emoji bitmap in upper 60%, text centered in lower 40%
    - Add OP_SET_ICON_TEXT (0x0A) BLE opcode with icon_id + color + text payload
    - Add icon_data.h: 8 pre-rendered emoji bitmaps as RGB565 PROGMEM arrays (225KB flash)
    - Add gen_icons.py tool to regenerate bitmaps from emoji using Pillow
    Service / UI:
    - Emoji picker in custom message panel (8 icons: none, meeting, wfh, oof, lunch, focus, back, busy)
    - Battery shows "USB / No battery" when reading is 0 and connected, instead of "0%"
    - Pass icon_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
    [ble_service.cpp, config.h, display.cpp]
2026-06-04 Add web UI log panel and fix image display pipeline
    Service:
    - Add log_buffer.py: MemoryLogHandler captures logs to in-memory deque
    - Add /api/logs GET (paginated) and DELETE (clear) endpoints
    - Add collapsible Logs panel in dashboard: auto-polls every 2s, color-coded
    by level, filterable, auto-scroll, error badge on summary
    - Fix STATE_CUSTOM_IMAGE not handled in main loop (was falling through to fillScreen)
    - Add ble_get_image_data/len/free() accessors for image buffer
    - Fix JPEGDEC pixel type: RGB565_BIG_ENDIAN -> RGB565_LITTLE_ENDIAN
    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
    [ble_service.cpp, display.cpp, main.cpp]
2026-06-04 Revert preset image sending pending JPEG firmware flash
    Preset states (IN_MEETING/WFH/OOF) reverted to simple OP_SET_PRESET
    opcodes to avoid JPEG decode crash on current firmware. Image-based
    preset rendering is ready but requires flashing the fixed firmware
    (display.cpp JPEG startWrite fix + STATE_CUSTOM_IMAGE main loop handler).
2026-06-04 Emoji on presets, preview modal, faster image transfer
    - Re-enable image rendering for IN_MEETING/WFH/OOF presets (matching web UI emoji)
    - Increase BLE chunk size 200→490 bytes (~2.5x faster transfer)
    - Add /api/preview endpoint: renders image and returns base64 JPEG without BLE send
    - Add preview modal to dashboard: Preview... button shows image, Send to Display confirms
    - Fix IMAGE_CHUNK offset: sequential append instead of chunk_idx*509
    - Switch to RGB565_LITTLE_ENDIAN (correct colors for SH8601)
    - Write one scanline at a time in JPEG draw callback (avoids QSPI DMA limit)
    - Clear screen before JPEG decode
    - ble_get_image_data/len/free accessors for main loop
    - Verif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
    [ble_service.cpp, display.cpp]
2026-06-04 Font size controls in preview, layout fixes, always-image custom text
    - Add font_size_override param to render_screen/_draw_centered_group
    - Preview modal: +/- buttons re-render image at chosen font size
    - Font size carried through to Send (same size displayed as previewed)
    - Fix text block height check: reject font size if total group exceeds screen
    - Consistent line height (font_size * 1.3) eliminates spacing variation
    - EMOJI_PAD buffer prevents emoji top-clipping (e.g. red circle)
    - Always use image codepath for custom text (no more tiny pixel font fallback)
2026-06-04 Replace hardcoded emoji buttons with full emoji-picker-element
    - Add emoji-picker-element web component via CDN (dark theme)
    - Picker opens inline as dropdown below the Pick emoji button
    - Selected emoji shown in button; None button clears selection
    - Works with any emoji in the full Unicode set
2026-06-04 Update README to reflect current working state
    - Document all implemented features (emoji, preview, font controls, etc.)
    - Add Windows USB driver fix instructions
    - Add Microsoft Graph app registration steps
    - Add ESP32 MAC address discovery instructions
    - Document configuration options table
    - Update display states table with emoji and colors
    - Add architecture notes (image transfer, BLE, power management)
2026-06-04 Add Google Calendar support with provider abstraction
    - Add CalendarProvider abstract base class (calendar_base.py)
    - Add GoogleCalendarProvider (google_calendar.py):
    - Device code flow (TV & Limited Input Devices OAuth2)
    - Detects IN_MEETING via opaque events
    - Detects WFH via Google Working Location (homeOffice type)
    - Detects OOF via native Out of Office event type
    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
2026-06-04 Add Calendar settings UI with inline auth flow
    - Settings panel now has a Calendar section with provider selector
    - Google Calendar: Client ID and Secret fields (shown only when Google selected)
    - Sign In / Re-authenticate button triggers device code flow inline
    - Device code URL and code display directly in settings — no page reload
    - Google credentials read from settings_store (editable via UI, no env restart needed)
    - Remove old separate auth banner (auth now lives in Settings)
2026-06-04 Remove old auth banner — auth now lives in Settings panel
2026-06-04 Reduce status poll lag and expand local setup docs
    - Status card now refreshes every 2s (was 5s via HTMX) by piggybacking
    onto the existing log poll using Promise.all — single cadence keeps
    BLE indicator, battery, and logs in sync with no extra requests
    - Removed standalone HTMX hx-trigger from status card div
    - README: expand Service section with step-by-step local setup guide
    (prerequisites, venv creation, .env table, run command, first-run auth)
    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
2026-06-04 Boot splash, precompiled presets, button reboot, brightness fix, BLE stability
    - Boot splash: 💡 Meeting Light screen on startup (boot_splash.h, gen_boot_splash.py)
    - Precompiled preset images: In a Meeting/WFH/OOF stored as JPEG byte arrays in
    firmware so boot button cycle shows pixel-identical images to BLE-sent versions
    (preset_images.h, gen_preset_images.py); display_show_preset uses these
    - PROGMEM fix: copy flash data to heap RAM before JPEGDEC decode (openRAM writes
    into the buffer as scratch space)
    - Boot button: tap cycles states, hold 3s reboots (polled detection, short/long
    press distinction on release)
    - PendingCommand.set_state flag: brightness-only BLE comma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
    [ble_service.cpp, display.cpp]
2026-06-05 Audio playback with embedded PCM samples and mute toggle
    - Fix audio distortion: write full PCM buffers in single i2s.write()
    instead of chunked writes that caused DMA underruns
    - Enable PA after I2S+codec init to avoid amplifying noise
    - Replace synthesized sine tones with real audio samples (MP3→PCM)
    embedded as C header arrays, high-pass filtered at 500Hz for the
    small speaker
    - Add 50ms silence flush after playback to prevent click artifacts
    - Add mute toggle: BLE opcode 0x0B, web UI button, RAM-only flag
    that resets on boot
    - Add run-service.ps1 helper script for quick local testing
    [audio.cpp, ble_service.cpp, config.h]
2026-06-05 USB/VBUS power detection, charging status, and dashboard fixes
    Add power_is_vbus_in() to firmware using AXP2101 PMIC, expand BLE
    status packet to 6 bytes with VBUS flag. Propagate charging and VBUS
    state through service to web dashboard — shows USB Powered, Charging,
    or battery % as appropriate. Fix duplicate BLE commands on reconnect
    by clearing pending state after send. Fix last_seen timestamp 3 hours
    off by sending ISO format and formatting client-side in local timezone.
    [ble_service.cpp, main.cpp, power.cpp]
2026-06-06 Add 3D-printed enclosure (STL + 3MF) and document in README
    Two-piece Fusion 360 case: front lid (flush screen recess, PIR cone
    aperture, paper nameplate frame) + back tray (mid-edge battery retention
    keeping corners clear for the JST wire, command-strip window mount),
    joined by a self-aligning rabbet lip with snap-in detents. Designed to
    print standing on end without supports. ~202x50x17mm.
    [BackTray.stl, FrontLid.stl, MeetingLight-Enclosure.3mf]
2026-06-07 Enclosure v9: fit fixes, captive buttons, 8in-class nametag
    Iterated the two-piece enclosure after a v8 test print:
    - Display window glass recess corners R2.0 -> R1.8 to match the
    screen glass (fixes corner light leak)
    - Battery moved to a full-height perimeter pocket on the front-lid
    back with a JST wire relief (old tray ribs were too small to hold it)
    - Continuous rib-in-groove snap replaces the weak point detents;
    length-matched so it also locks out the left/right slide
    - Screen flipped: USB-C + 2 button openings on the outer end wall,
    plus separate captive button caps (base inside, 4mm stem)
    - Display recentered between the outer wall and PIR; PIR relocated so
    it no longer sits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
    [BackTray.stl, ButtonCap.stl, FrontLid.stl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]
2026-06-09 Add waiting screen, 180° rotation, per-device BLE name, and timer sleep
    - Rotate display 180° (rotation=2) so buttons are on the left, accessible
    from the enclosure cutout
    - Add "Waiting to Connect" screen after boot splash: shows Bluetooth logo
    (120x120 icon from PNG) and full BLE MAC address on black background
    - Per-device BLE advertised name: MeetingLight-XXXX (last 2 MAC bytes),
    set via NimBLEDevice::setDeviceName() after init
    - Add ble_get_mac_address() returning uppercase colon-separated MAC string
    - Boot phase state machine: BOOT_SPLASH (5s) -> BOOT_WAITING -> BOOT_DONE;
    timer wakes skip splash/audio and go straight to connect screen
    - Fix deep sleep wakeup: GPIO 9/15 are H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
    [ble_service.cpp, display.cpp, main.cpp]
2026-06-09 Simplify calendar auth — credentials as deployment config, not source
    Each user signs in with their own account via the existing device-code flow.
    Credentials are now deployment configuration only (via .env passed through
    docker-compose env_file), never baked into source or the compose file.
    - Remove Google client ID/secret inputs from the settings UI (dashboard.html,
    app.py) — credentials are deployment config, not runtime user input
    - Fix MS Graph tenant default: common → organizations (device-code flow
    requires /organizations for work/school accounts)
    - Fix Google credential fallback to skip empty settings.json overrides and
    use the env var value instead
    - Update .env.example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
2026-06-10 Fix Microsoft OAuth setup instructions for current Entra ID portal
    The old steps were missing the 'Allow public client flows' toggle
    (required for device-code flow) and used outdated Azure AD navigation.
    Updated to match the current portal UI with numbered steps and a
    tenant ID note for personal vs work accounts.
2026-06-10 Add Available state, calendar info card, and Proxmox deployment
    - New AVAILABLE (7) firmware preset: ☀️ amber screen shown when in the
    office with no active meeting; baked into firmware like WFH/OOF/Meeting
    - State detection priority reordered: WFH (work location API) → OOF →
    In a Meeting → Available; reads Teams presence workLocationType field
    - Calendar info card on dashboard: signed-in user, Teams presence with
    work location label, and next 5 upcoming meetings
    - BLE: AVAILABLE now sends OP_SET_PRESET instead of custom image transfer
    - Firmware guard updated to allowlist preset state IDs (prevents invalid
    states like CUSTOM_TEXT from being set via OP_SET_PRESET)
    - README: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
    [ble_service.cpp, config.h, display.cpp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]
2026-06-10 Add provider icon to calendar tile, show free/working-location events
    - Calendar tile now shows the Microsoft (4-color grid) or Google G
    icon next to the signed-in user's name
    - Upcoming events no longer filters out showAs=free, so working
    location events (WFH Thursday etc.) appear in the list; top raised
    to 8 to compensate; free events get a gray dot
2026-06-11 Fix BLE connection reliability, emoji presets, and calendar bugs
    - BLE: scan with find_device_by_address before connecting so Windows
    WinRT BLE cache is warm; raise connection timeout to 30s; log exception
    type so silent TimeoutError is visible; tighten advertising max interval
    100ms→200ms for faster initial handshake
    - Preset images: regenerate with Windows Segoe UI Emoji font so emoji
    render correctly; change Available background from amber to green (#1CA800)
    - Available override button added to dashboard; Clear Override moved to
    slim full-width button below the preset grid
    - Calendar poll: fix 'NoneType has no attribute get' when Graph API returns
    workLocation: null (key pre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
    [ble_service.cpp]
2026-06-11 Add PIR press-through mount + guide collar to enclosure v11
    Stepped PIR aperture (Ø8.49 can hole + Ø9.5 brim counterbore on a 1mm
    shoulder), a slotted round guide collar that captures the 10x7.88 sensor
    PCB, and a 0.6mm lead-in chamfer. Battery pocket shifted +1mm for
    clearance. All parametric; F3D archive captures full timeline + params.
    [MeetingLight-Enclosure-v11.f3d]
2026-06-20 Add 3-piece enclosure (magnetic cover, snap-in door/hinge) + firmware/service updates
    Enclosure (Fusion "Meeting Light Enclosure (parametric)" v37):
    - 3-piece design: full-length snap-in back retainer, middle shell, and a
    swappable magnetic front cover (coved screen + PIR openings, 4x 6x2mm magnets)
    - Separate battery door: snap-on C-clip hinge over the integral pin, U-clip latch
    with a parametric press-fit knob (latch_press); cradle clearance for removal
    - SR602 PIR mount: enlarged collar bore so the PCB seats, taller +-X key posts
    - Updated Bambu project 3MF (merged geometry in-place, preserving the 2-plate layout)
    - Nameplate template tooling + assembly/service docs
    - gitignore esptoo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
    [Back Tray.stl, BackTray.stl, ButtonCap.stl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]
